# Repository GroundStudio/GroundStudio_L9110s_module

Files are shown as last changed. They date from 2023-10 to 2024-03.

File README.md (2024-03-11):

GroundStudio L9110s Dual Motor Driver Module
====================================
L9110s module REV0 0 2

Get it from [ardushop.ro](https://ardushop.ro/ro/home/2525-modl9110s.html)

Explore all the GroundStudio products at [GroundStudio.ro](https://groundstudio.ro/)

Description
-------------------
Dual motor driver module based on two L9110S chips.

Contents
-------------------

* [/Documentation](https://github.com/GroundStudio/GroundStudio_L9110s_module/tree/main/Documentation) -- Contains documentation written during creation of this repository, with readme.md index of its own!
* [/Firmware](https://github.com/GroundStudio/GroundStudio_L9110s_module/tree/main/Firmware) -- Firmware (bootloaders, etc)
* [/Hardware](https://github.com/GroundStudio/GroundStudio_L9110s_module/tree/main/Hardware) -- Schematics, layout.
* [/Libraries](https://github.com/GroundStudio/GroundStudio_L9110s_module/tree/main/Libraries) -- Arduino/CircuitPython libraries. 
* [/Tools](https://github.com/GroundStudio/GroundStudio_L9110s_module/tree/main) -- Tools needed for compiling, uploading bootloader, etc.

Versions
-------------------
*(Not all tags shown)*
* [V0.0.2] Initial version

License
-------------------

This is released under the [Attribution-ShareAlike 4.0 International (CC BY-SA 4.0)](https://creativecommons.org/licenses/by-sa/4.0/) license. 
**You are welcome to use this for commercial purposes.**

Please consider contributing back to this project or others to help the open-source hardware community continue to thrive and grow! 

Certifications:

[Open Source Hardware Association](https://certification.oshwa.org/ro000014.html)   
   
certification-mark-RO000014-wide (https://certification.oshwa.org/ro000014.html)

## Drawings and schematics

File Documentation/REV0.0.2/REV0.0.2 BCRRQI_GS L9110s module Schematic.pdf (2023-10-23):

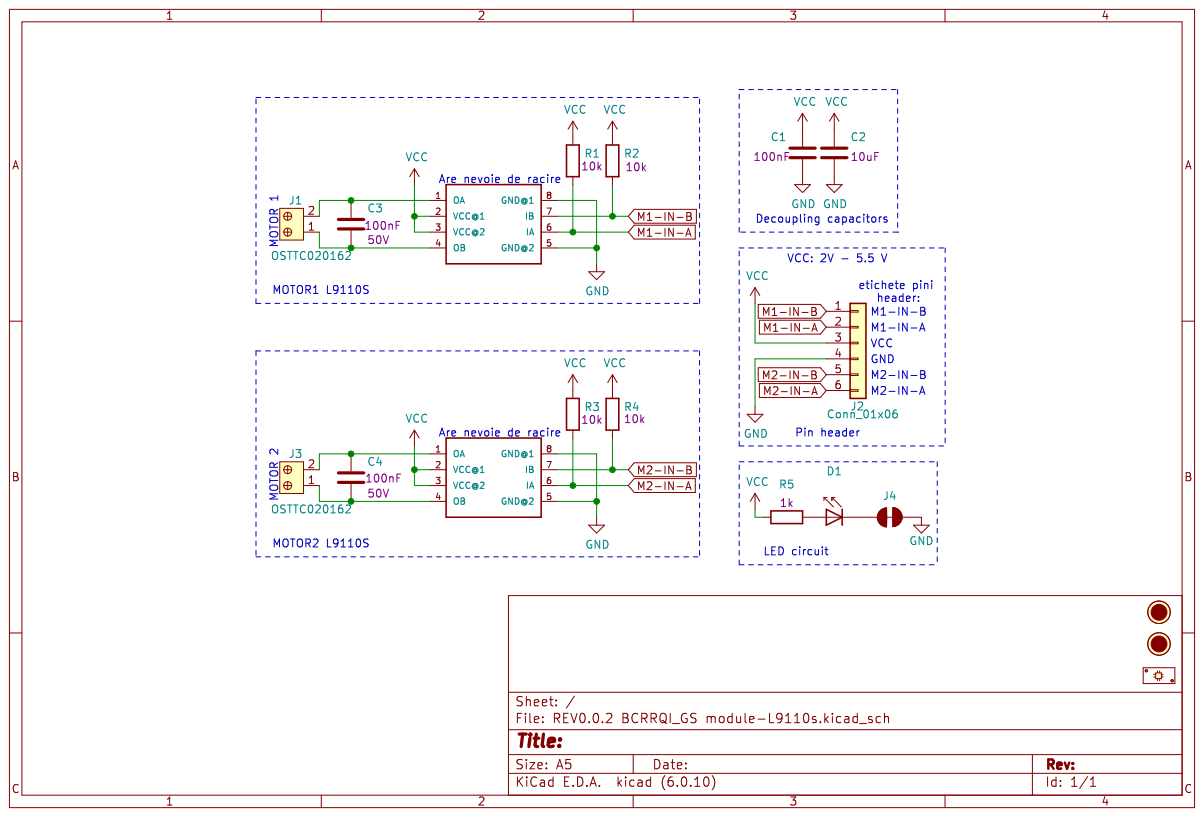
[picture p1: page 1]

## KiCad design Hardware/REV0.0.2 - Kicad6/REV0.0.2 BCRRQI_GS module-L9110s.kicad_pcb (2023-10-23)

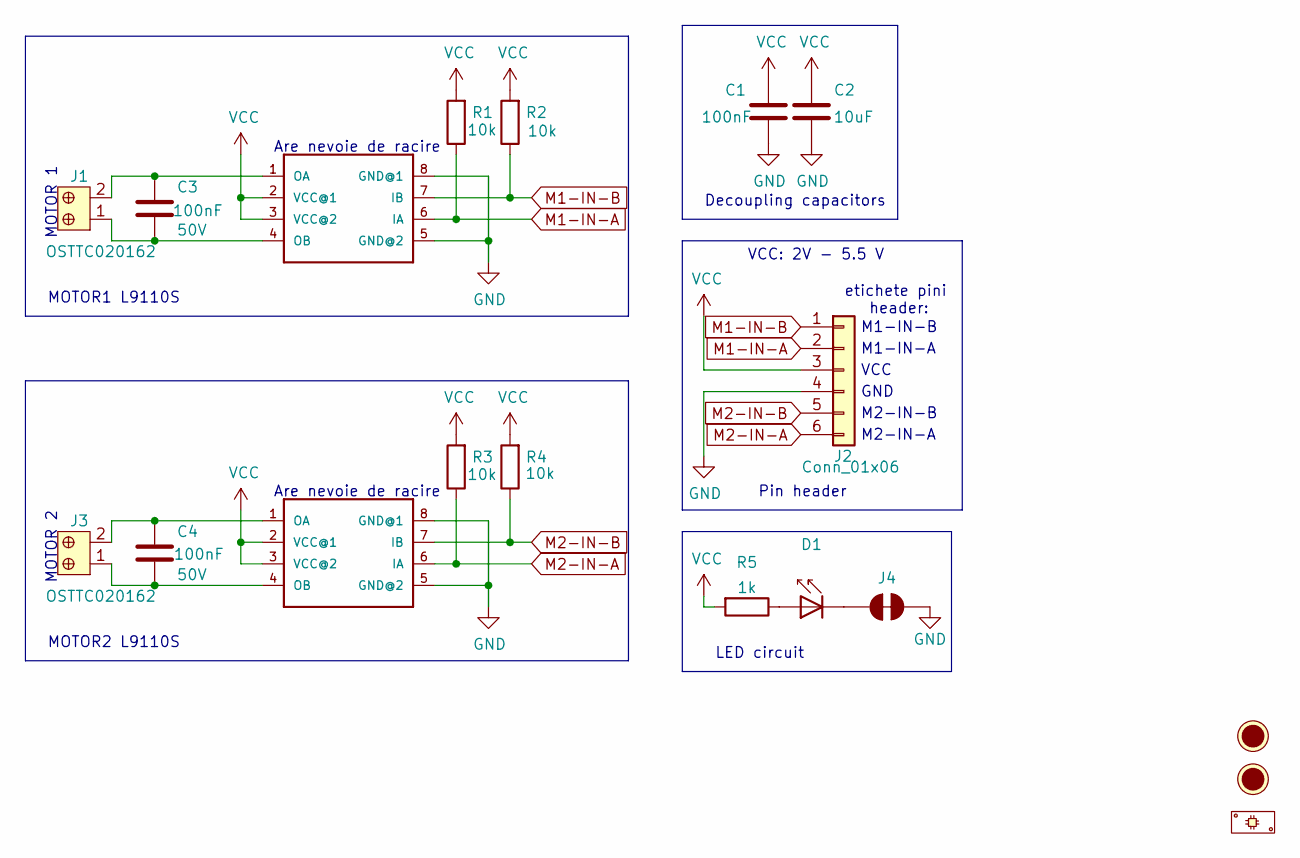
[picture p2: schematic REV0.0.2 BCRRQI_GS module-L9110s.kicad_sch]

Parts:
C1, C3, C4: C_0603_100nF_50V; C_0603; Rated voltage 50V; MPN TCC0603X7R104K500CT; LCSC C282519
C2: C_1206_10uF_25V; C_1206; Rated voltage 25V; MPN CL31B106KAHNNNE; LCSC C14860
D1: LED_0402_RED; LED_0402; MPN TZ-P2-0402RTIA1-0.45T; LCSC C779449
FID1, FID2: Fiducial; Fiducial_0.75mm_Mask1.5mm
J1, J3: OSTTC020162; WJ126V-5.0-2P; MPN WJ126V-5.0-2P; LCSC C8404
J2: Conn_01x06; PinHeader_1x06_P2.54mm_Vertical_Male; MPN C37208; LCSC C37208
J4: PWR LED DISABLE; SolderJumper_NC
P1: PCB; MPN BCRRQI_GS_PCB
R1, R2, R3, R4: R_0402_10k; R_0402; MPN 0402WGJ0103TCE; LCSC C25531
R5: R_0402_1k; R_0402; MPN RC-02W1001FT; LCSC C226166
U1, U2: L9110; SOIC-8_3.9x4.9mm_P1.27mm; MPN L9110S; LCSC C85174

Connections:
GND: C1.1, C2.2, J2.4, J4.1, U1.5 (GND@2), U1.8 (GND@1), U2.5 (GND@2), U2.8 (GND@1)
M1-IN-A: J2.2, R1.1, U1.6 (IA)
M1-IN-B: J2.1, R2.1, U1.7 (IB)
M2-IN-A: J2.6, R3.1, U2.6 (IA)
M2-IN-B: J2.5, R4.1, U2.7 (IB)
unnamed: C3.1, J1.2, U1.1 (OA)
unnamed: C3.2, J1.1, U1.4 (OB)
unnamed: C4.1, J3.2, U2.1 (OA)
unnamed: C4.2, J3.1, U2.4 (OB)
unnamed: D1.1 (K), J4.2
unnamed: D1.2 (A), R5.1
VCC: C1.2, C2.1, J2.3, R1.2, R2.2, R3.2, R4.2, R5.2, U1.2 (VCC@1), U1.3 (VCC@2), U2.2 (VCC@1), U2.3 (VCC@2)

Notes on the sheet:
VCC
MOTOR2 L9110S
Are nevoie de racire
Decoupling capacitors
M1-IN-B
GND
VCC: 2V - 5.5 V
M2-IN-B
MOTOR1 L9110S
LED circuit
M1-IN-A
MOTOR 1
M2-IN-A
MOTOR 2
Pin header
etichete pini header:

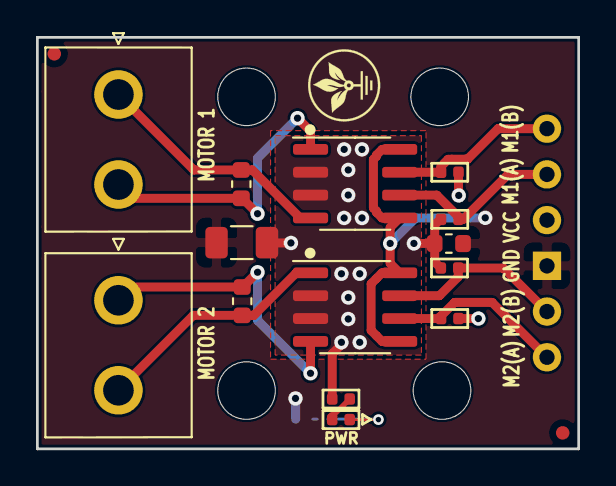
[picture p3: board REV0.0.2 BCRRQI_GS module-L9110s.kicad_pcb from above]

Board: 2 copper layers, 30.1 x 22.9 mm, 18 parts (1 on the bottom side), 12 nets.
